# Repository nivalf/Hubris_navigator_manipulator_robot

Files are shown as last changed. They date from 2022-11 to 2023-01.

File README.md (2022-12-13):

# Hubris_navigator_manipulator_robot
Task:
- Navigate to the white board
- Draw on the whiteboard
- Return home

## Navigation Modes:
### 1. Curved path
- Move forward in a calculated curved path
- On detecting black line turn left & orient the bot to 90 degree from the start position.
- Move forward and draw on the whiteboard
- Reverse the bot again in a clockwise curve followed by a counter clockwise turn to reach the next black line.
- On detecting black line orient 90 degree and move backwards to reach home

IR Sensors: to detect black line
Ultrasound Sensors: to slow down the bot at a set distance from the whiteboard
Encoders: for odemetry

### 2. Using IR & Ultrasonic
- Navigate in straight lines & make 90 degree turns. 
- Detect black lines using IR 
- Ultrasonic is used to slow down the bot at set distances

### 3. Using only Ultrasonic
- Navigation by only using ultrasonic sensor readings

### 4. Using only IR
- Line follower

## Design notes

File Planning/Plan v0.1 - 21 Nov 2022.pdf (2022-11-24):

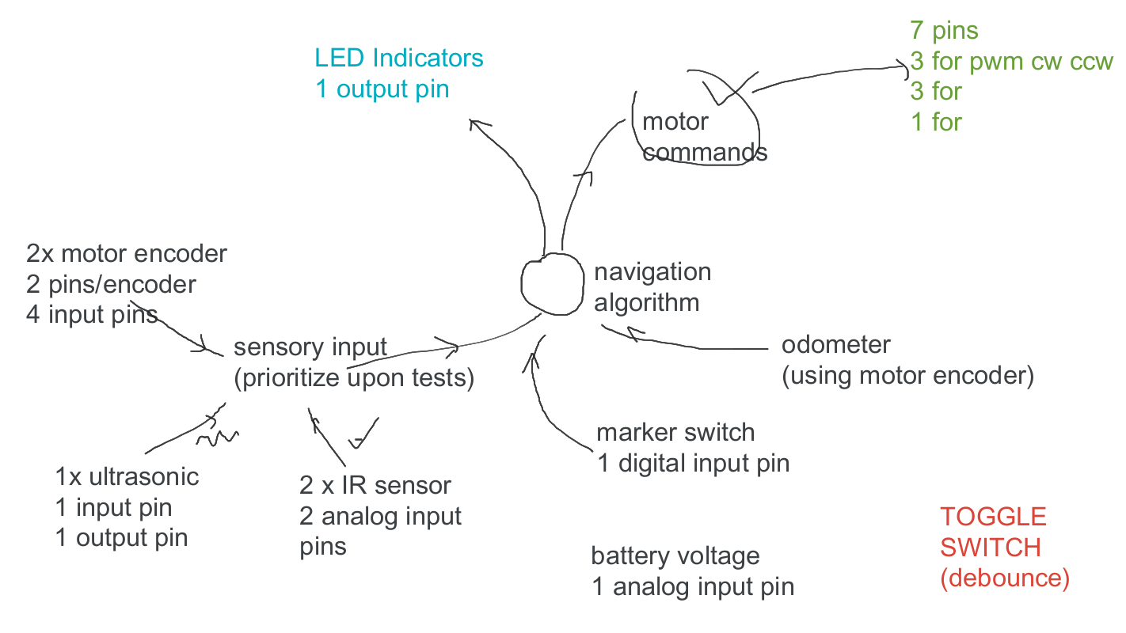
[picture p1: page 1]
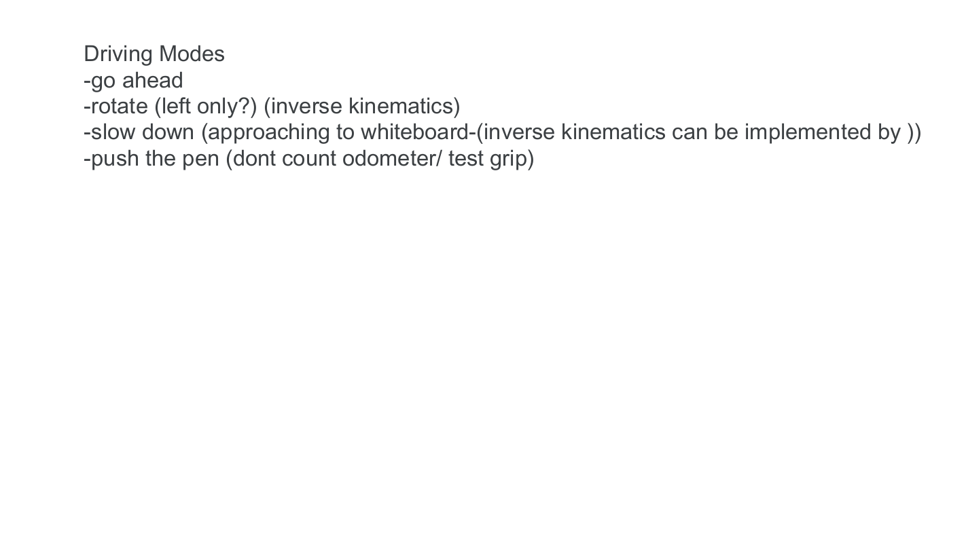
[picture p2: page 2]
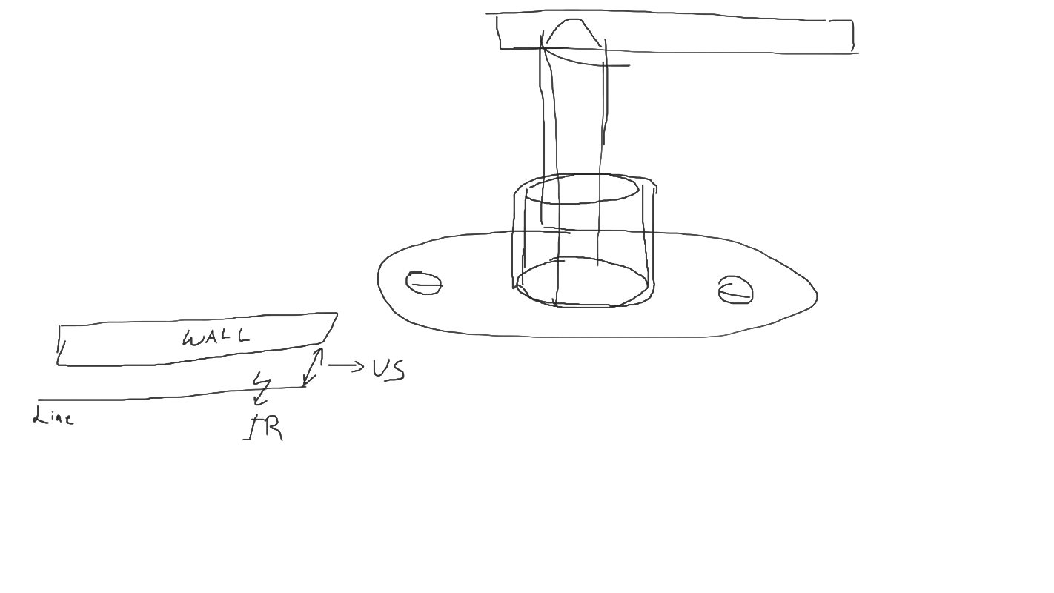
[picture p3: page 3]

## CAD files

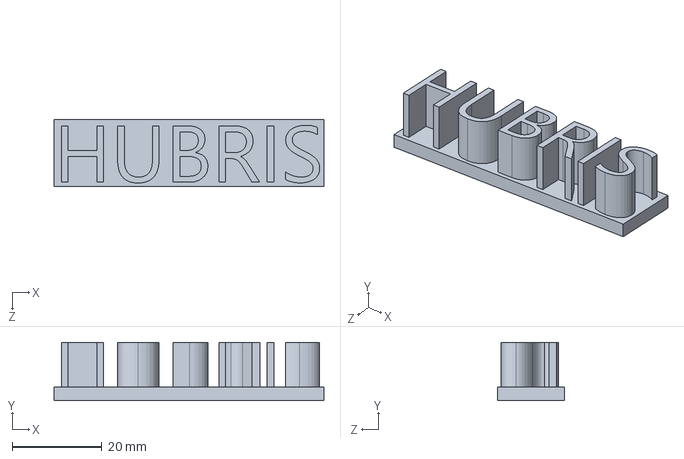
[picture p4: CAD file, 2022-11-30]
Design/CAD and DXF Files v4/Part2.SLDPRT
60.0 x 13.0 x 15.0 mm

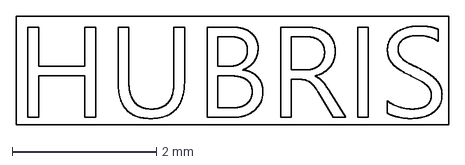
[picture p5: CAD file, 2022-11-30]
Design/CAD and DXF Files v4/Engraving.DXF
6.00 x 1.50 mm

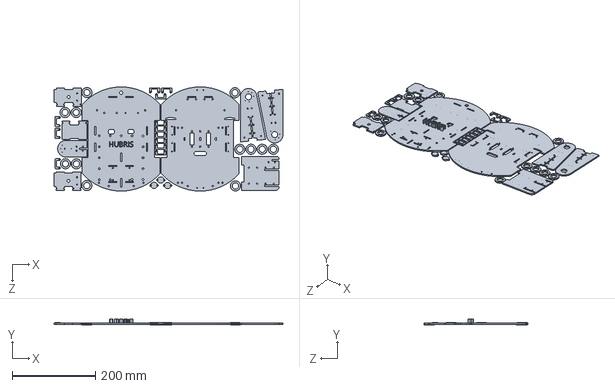
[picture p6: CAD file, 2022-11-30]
Design/CAD and DXF Files v4/lasercuttinglayout.SLDPRT
549.7 x 14.5 x 250.0 mm

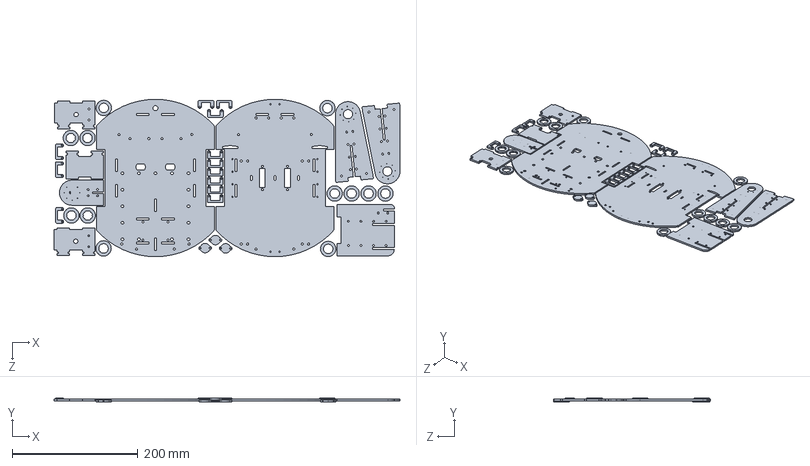
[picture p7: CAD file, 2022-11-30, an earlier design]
Design/CAD and DXF Files v2/lasercuttinglayout.SLDPRT
549.7 x 6.00 x 250.0 mm

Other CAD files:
Design/CAD and DXF Files v3/lasercuttinglayout.SLDPRT
Design/CAD and DXF Files/lasercuttinglayout.SLDPRT
Design/CAD and DXF Files v2/lasercuttinglayout.DXF
Design/CAD and DXF Files v3/lasercuttinglayout.DXF
Design/CAD and DXF Files v4/lasercuttinglayout.DXF
Design/CAD and DXF Files/lasercuttinglayout.DXF

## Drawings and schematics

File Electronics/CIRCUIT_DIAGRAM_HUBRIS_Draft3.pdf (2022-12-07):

## GND

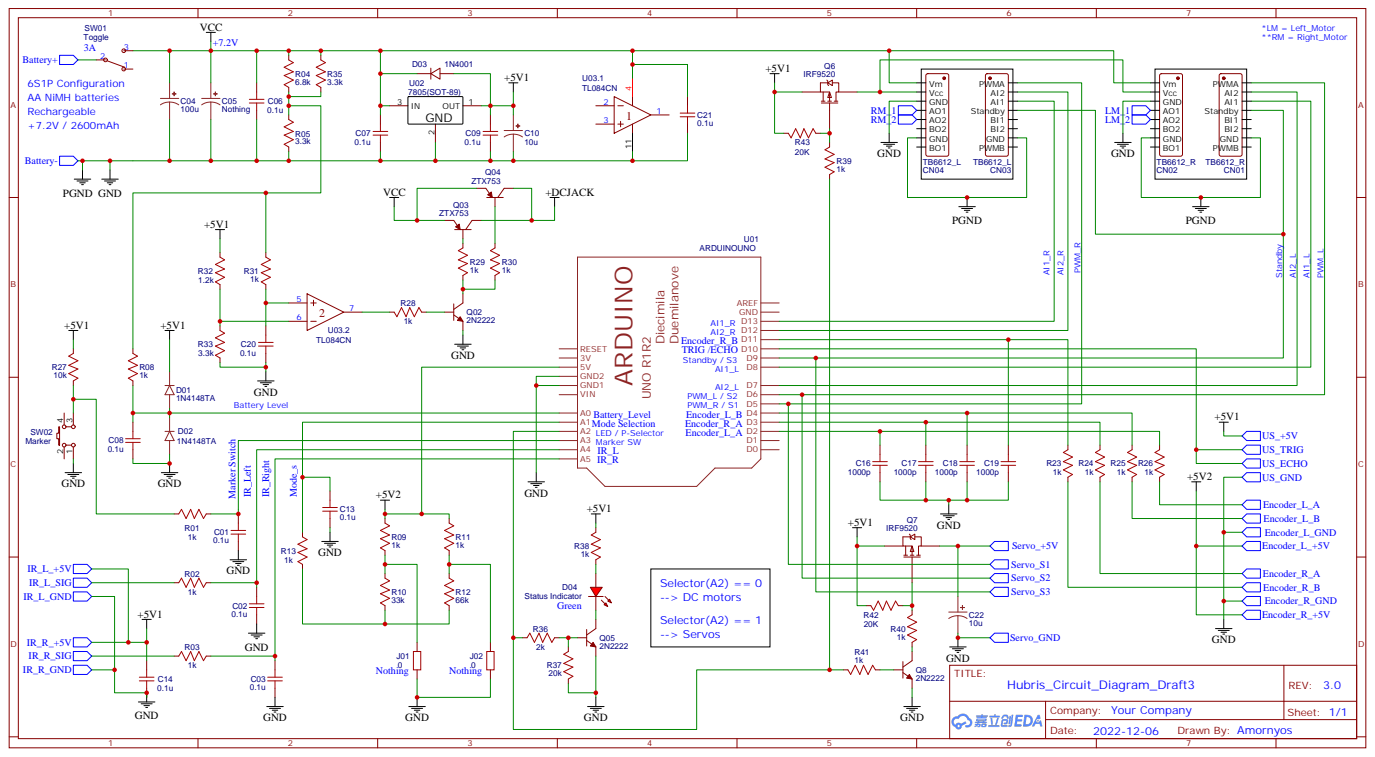
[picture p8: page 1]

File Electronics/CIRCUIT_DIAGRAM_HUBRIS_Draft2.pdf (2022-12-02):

## GND

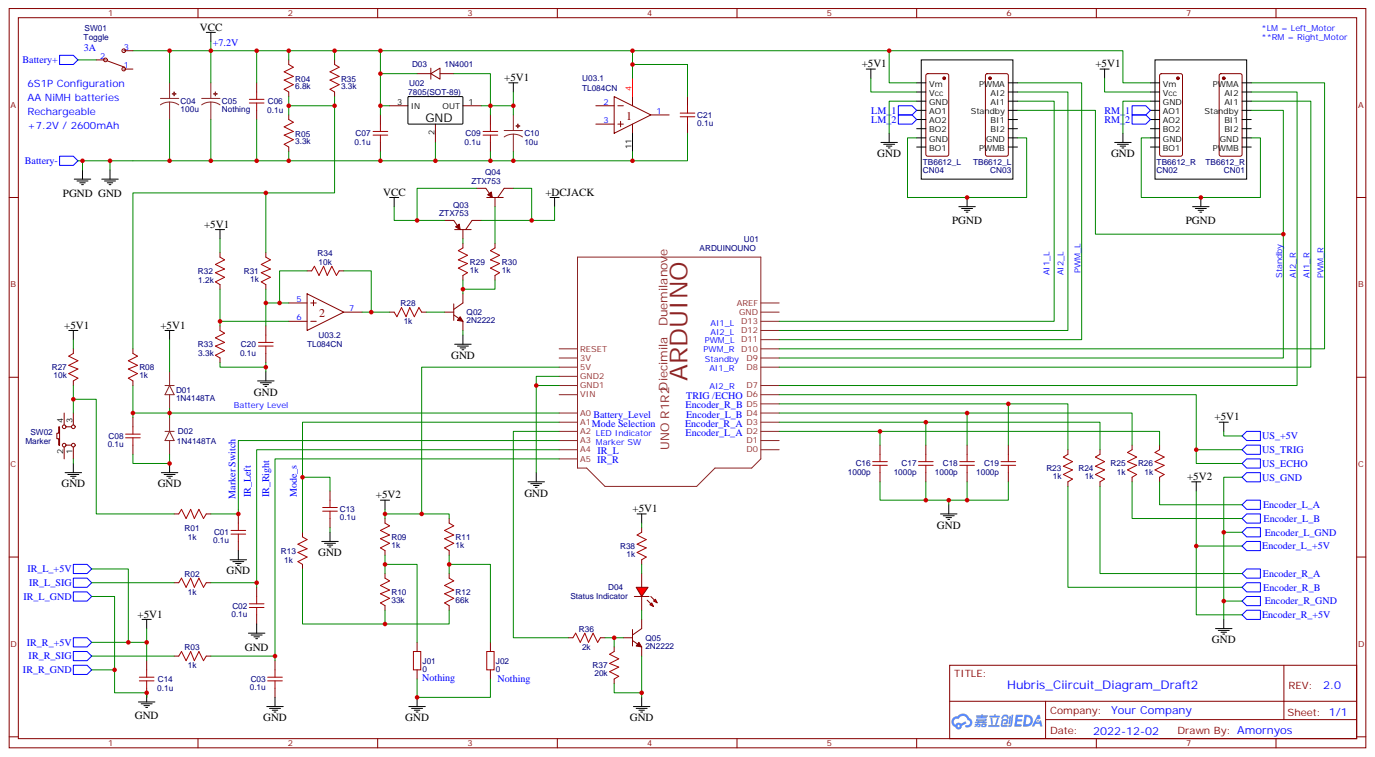
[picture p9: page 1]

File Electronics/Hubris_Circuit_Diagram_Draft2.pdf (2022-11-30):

## GND

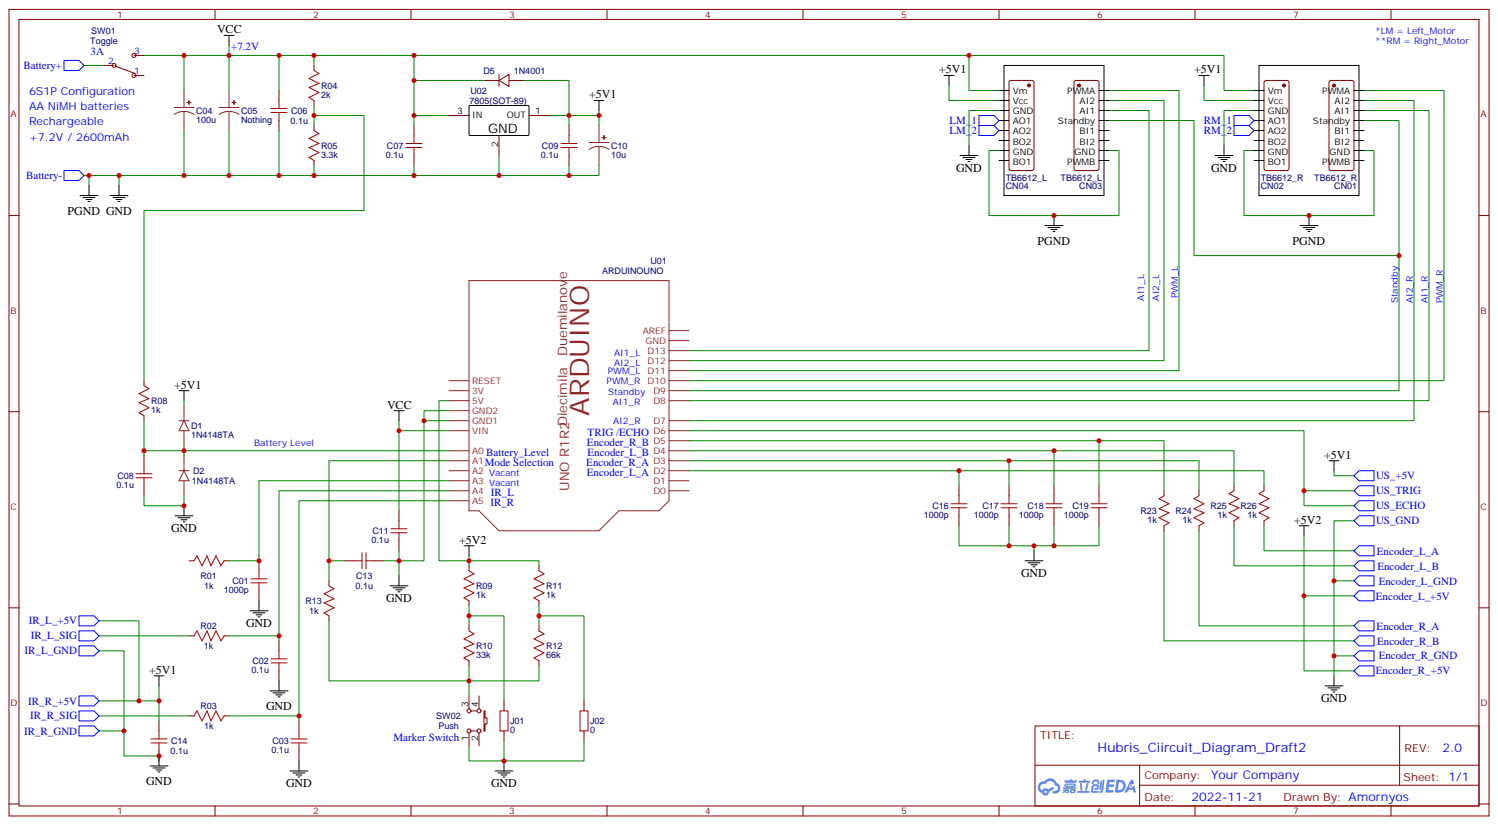
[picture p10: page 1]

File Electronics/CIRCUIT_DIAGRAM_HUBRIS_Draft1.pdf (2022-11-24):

## GND

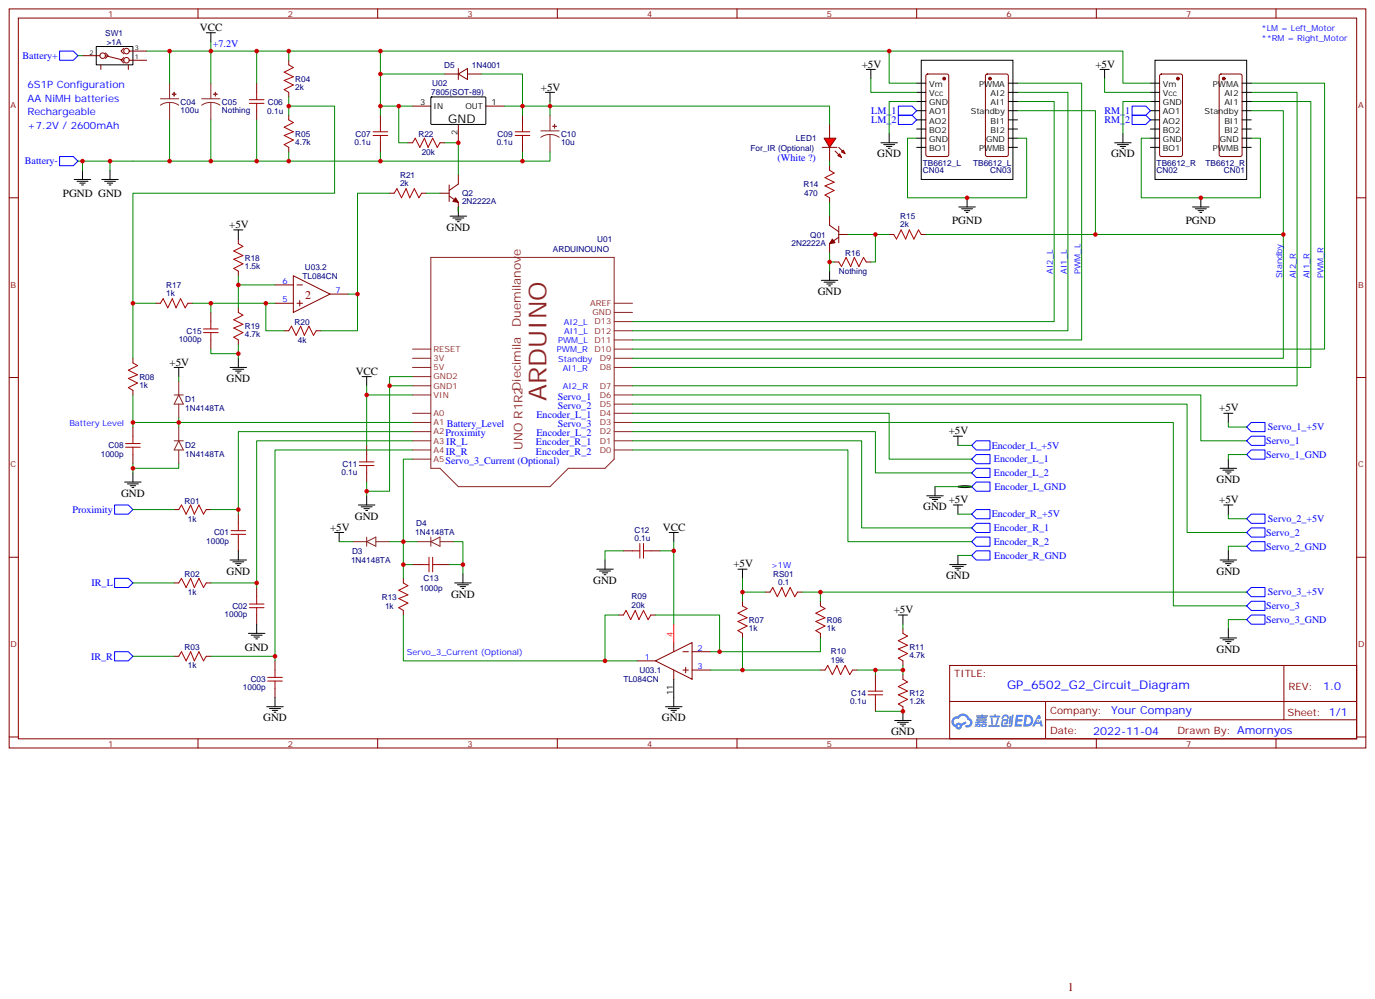
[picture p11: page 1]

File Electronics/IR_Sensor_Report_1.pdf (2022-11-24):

## Sharp's IR sensor performance evaluation report (1)

As the testing of IR sensor on the arena on the last Tuesday, It seemed that when the sensor passed through the black track, the ADC value would jump up from about 300 to 500 depend on the distance between sensors and the ground. (about 1.5 cm?) In this report, The closer of IR sensor to the track have been tested. And the result turned out that when the sensors passed through the black track, The ADC would drop from about 300 to 3 which is a big jump. This may help to decide the position of the sensors. The plotted results is shown in the second page.

Test condition 1 : 14.5 mm (1.45 cm)

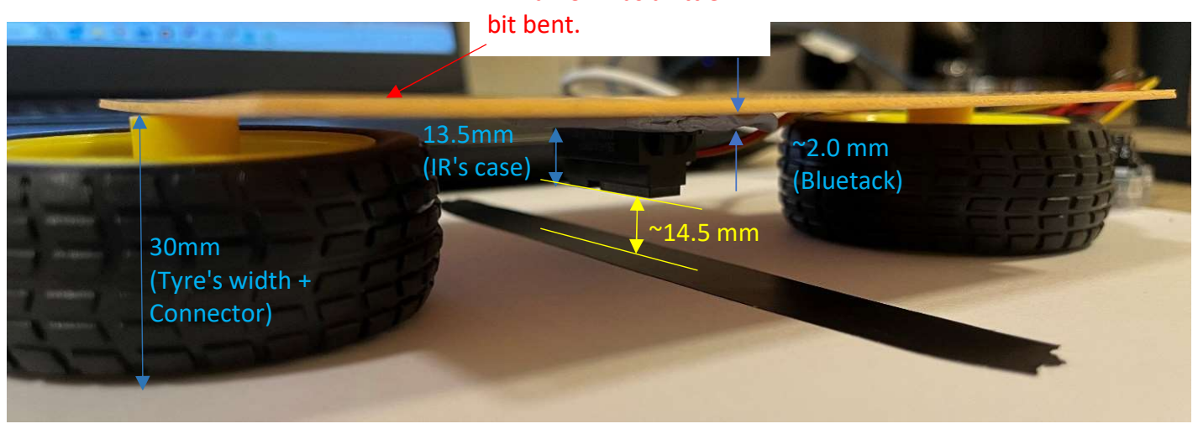
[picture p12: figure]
30mm (Tyre's width + Connector); 13.5mm (IR's case); ~2.0 mm (Bluetack); bit bent.

Test condition 2 : 11.5 mm (1.15cm)

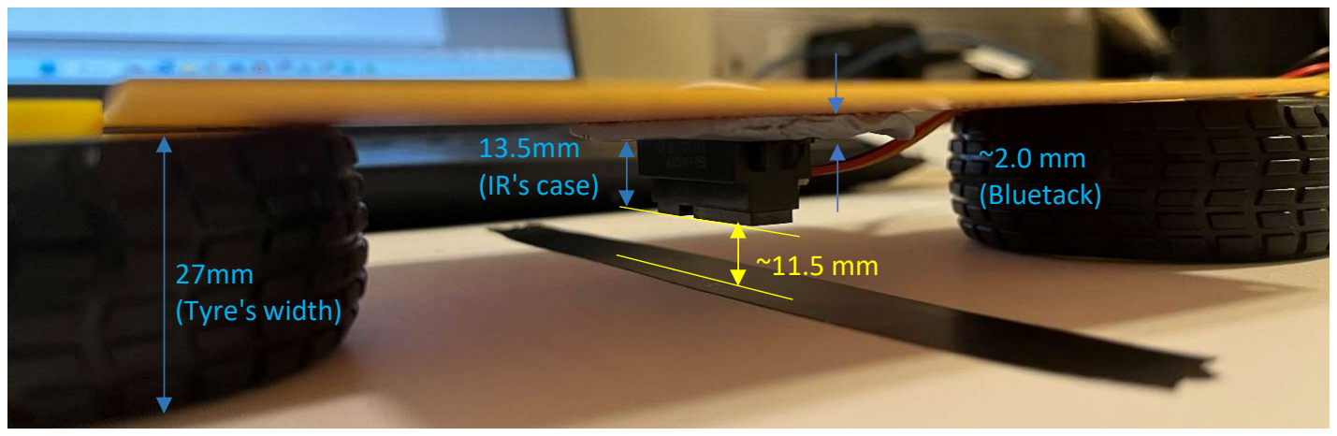
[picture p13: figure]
27mm (Tyre's width); 13.5mm (IR's case); ~2.0 mm (Bluetack)

Test condition 3 : 4.5mm (0.45cm)

*** a PCB was a little

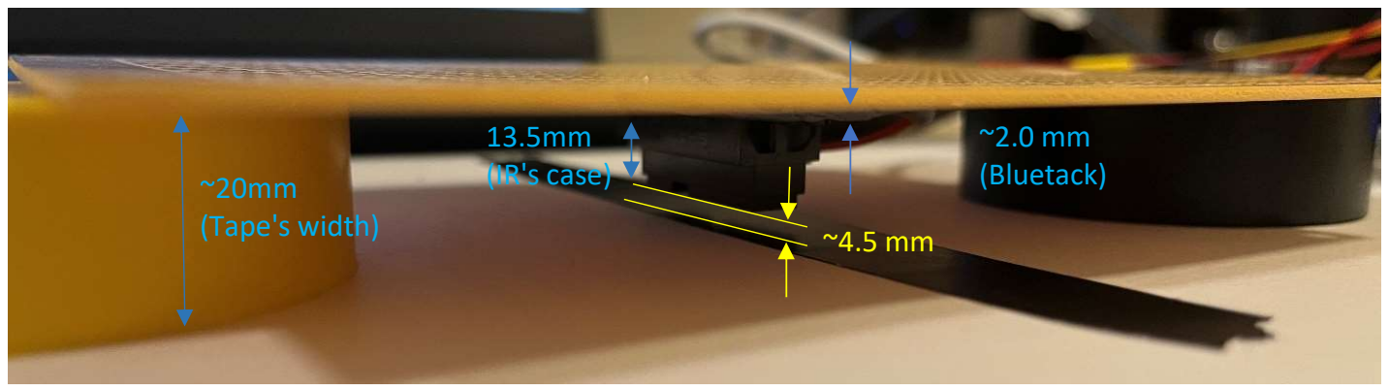
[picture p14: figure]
~20mm (Tape's width); 13.5mm (IR's case); ~2.0 mm (Bluetack)

## Test result

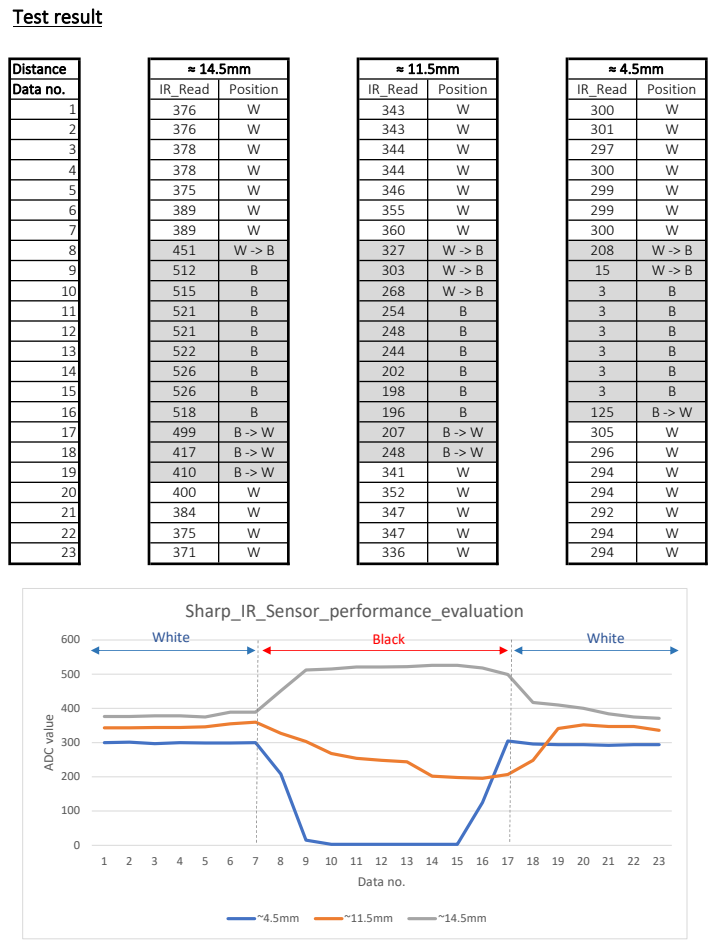
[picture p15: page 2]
Distance; Data no.; IR_Read; Position; 9 10 11 12 13 14 15 16 17 18 19 20 21 22 23 ADC value; Sharp_IR_Sensor_performance_evaluation; White; Black

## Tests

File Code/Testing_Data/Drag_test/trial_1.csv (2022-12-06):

Speed | Stopped_wheel | Encoder_R | Encoder_L | Rotation_R | Rotation_L | Stopped_wheel | Encoder_R | Encoder_L | Rotation_R | Rotation_L | Drag | Encoder_R | Encoder_L | Rotation_R | Rotation_L
20 | Right | 970 | 865 | 1.00 | 0.89 | Left | 975 | 970 | 1.01 | 1.00 | Drag | 0 | 1 | 0.00 | 0.00
30 | Right | 970 | 880 | 1.00 | 0.91 | Left | 983 | 970 | 1.01 | 1.00 | Drag | 0 | 8 | 0.00 | 0.01
40 | Right | 970 | 865 | 1.00 | 0.89 | Left | 994 | 970 | 1.02 | 1.00 | Drag | 0 | 15 | 0.00 | 0.02
50 | Right | 970 | 896 | 1.00 | 0.92 | Left | 1004 | 970 | 1.04 | 1.00 | Drag | 1 | 25 | 0.00 | 0.03
60 | Right | 970 | 881 | 1.00 | 0.91 | Left | 1016 | 970 | 1.05 | 1.00 | Drag | 2 | 32 | 0.00 | 0.03
70 | Right | 970 | 932 | 1.00 | 0.96 | Left | 999 | 970 | 1.03 | 1.00 | Drag | 25 | 48 | 0.03 | 0.05
80 | Right | 970 | 875 | 1.00 | 0.90 | Left | 1032 | 970 | 1.06 | 1.00 | Drag | 16 | 58 | 0.02 | 0.06
90 | Right | 970 | 869 | 1.00 | 0.90 | Left | 1041 | 970 | 1.07 | 1.00 | Drag | 24 | 61 | 0.02 | 0.06
100 | Right | 970 | 885 | 1.00 | 0.91 | Left | 1037 | 970 | 1.07 | 1.00 | Drag | 38 | 76 | 0.04 | 0.08
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

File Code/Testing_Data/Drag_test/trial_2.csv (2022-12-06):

Speed | Stopped_wheel | Encoder_R | Encoder_L | Rotation_R | Rotation_L | Stopped_wheel | Encoder_R | Encoder_L | Rotation_R | Rotation_L | Encoder_R_Drag | Encoder_L_Drag | Rotation_R_Drag | Rotation_L_Drag
20 | Right | 970 | 851 | 1.00 | 0.88 | Left | 974 | 970 | 1.00 | 1.00 | 0 | 2 | 0.00 | 0.00
30 | Right | 970 | 870 | 1.00 | 0.90 | Left | 984 | 970 | 1.01 | 1.00 | 0 | 8 | 0.00 | 0.01
40 | Right | 970 | 885 | 1.00 | 0.91 | Left | 994 | 970 | 1.02 | 1.00 | 0 | 16 | 0.00 | 0.02
50 | Right | 970 | 885 | 1.00 | 0.91 | Left | 1006 | 970 | 1.04 | 1.00 | 0 | 26 | 0.00 | 0.03
60 | Right | 970 | 892 | 1.00 | 0.92 | Left | 1013 | 970 | 1.04 | 1.00 | 5 | 36 | 0.01 | 0.04
70 | Right | 970 | 959 | 1.00 | 0.99 | Left | 980 | 970 | 1.01 | 1.00 | 44 | 51 | 0.05 | 0.05
80 | Right | 970 | 902 | 1.00 | 0.93 | Left | 1020 | 970 | 1.05 | 1.00 | 28 | 65 | 0.03 | 0.07
90 | Right | 970 | 888 | 1.00 | 0.92 | Left | 1033 | 970 | 1.06 | 1.00 | 35 | 69 | 0.04 | 0.07
100 | Right | 970 | 887 | 1.00 | 0.91 | Left | 1035 | 970 | 1.07 | 1.00 | 41 | 83 | 0.04 | 0.09
120 | Right | 970 | 909 | 1.00 | 0.94 | Left | 1023 | 970 | 1.05 | 1.00 | 85 | 110 | 0.09 | 0.11
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

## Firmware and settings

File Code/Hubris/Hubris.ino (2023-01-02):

#include "Robot.h"
#include "Constants.h"

// IR pins
#define IRLeftAPin A5
#define IRRightAPin A4

#define markerSwitchPin A3
// BatteryVoltage
#define batteryVoltagePin A0
// use same pin for trig & echo
#define trigPin 10  // 6
#define echoPin 10

// pins for left motor
#define motorLeftPin1 7
#define motorLeftPin2 8
#define motorLeftStandbyPin 9
#define motorLeftPWMPin 6 //10
#define motorLeftEncoderChannel_A_Pin 2
#define motorLeftEncoderChannel_B_Pin 4
// pins for right motor
#define motorRightPin1 12
#define motorRightPin2 13
#define motorRightStandbyPin 9
#define motorRightPWMPin 5 // 11
#define motorRightEncoderChannel_A_Pin 3
#define motorRightEncoderChannel_B_Pin 11 // 5

#define lineFollowSpeed 40

Robot Hubris(IRLeftAPin, IRRightAPin, trigPin, echoPin, motorLeftPin1, motorLeftPin2, motorLeftStandbyPin, motorLeftPWMPin, motorLeftEncoderChannel_A_Pin, motorLeftEncoderChannel_B_Pin, motorRightPin2, motorRightPin1, motorRightStandbyPin, motorRightPWMPin, motorRightEncoderChannel_A_Pin, motorRightEncoderChannel_B_Pin, batteryVoltagePin, markerSwitchPin);

long timestamp;
int count = 0;

// ISRs : Interrupt Service Routines
void motorLeftISR() {
  Hubris.countLeftEncoderChannel_A();
}

void motorRightISR() {
  Hubris.countRightEncoderChannel_A();
}

void setup(void) {
  Serial.begin(9600);  // We'll send debugging information via the Serial monitor

  //Attaching interrupt to pins for encoder
  attachInterrupt(digitalPinToInterrupt(motorLeftEncoderChannel_A_Pin), motorLeftISR, RISING);
  attachInterrupt(digitalPinToInterrupt(motorRightEncoderChannel_A_Pin), motorRightISR, RISING);

  Hubris.init();

  // DEV NOTE: Remove when not testing
  delay(1000);
}

void loop(void) {
  /*  
    Write your code here. You may use to curePath.ino and the other .ino files for reference.
    However, it is not required to write another .ino file, instead the code can be written directly here. 

    Go through the libraries folder to find the classes for each component: Hubris, left motor, right motor.. Feel free to 
    play with the individual functions or write them from scratch. I thought to delete those functions before handing this 
    over to you, but instead it might be better to have them for reference. You can choose to rewrite or modify as required.

    Happy Coding!
  */
}

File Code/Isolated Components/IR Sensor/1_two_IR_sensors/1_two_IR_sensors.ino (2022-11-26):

 
int IR1AnalogPin = A4; // IR is connected to analog 1
int IR2AnalogPin = A5; // IR is connected to analog 1
float IR1Reading;      // the analog reading from the IR sensor
float IR2Reading;      // the analog reading from the IR sensor
 
void setup(void) {
  Serial.begin(9600);   // We'll send debugging information via the Serial monitor
}
 
void loop(void) {
  int count = 100;

  IR1Reading = 0;
  IR2Reading = 0;

  for(int i=0; i<count; i++) {
    IR1Reading += analogRead(IR1AnalogPin);
    IR2Reading += analogRead(IR2AnalogPin);
    delay(1);
  }

  // Get the average value
  IR1Reading = IR1Reading/count;
  IR2Reading = IR2Reading/count;
  
  Serial.print(IR1Reading);
  Serial.print(' ');
  Serial.print(IR2Reading);
  Serial.println(' ');
}

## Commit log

2022-11-24 Circuit diagram added, IR and ultrasonic codes added
2022-11-26 Class created for IR sensors
2022-11-26 Class Ultrasonic created
2022-11-26 Use single pin for ultrasonic reading
2022-11-26 Make the ultrasonic class inherited from NewPing
2022-11-26 Exponential avg filter added. Low pass filter added
2022-11-27 Motor class added
2022-11-28 Robot: Steering function added
    [lasercuttinglayout.DXF, lasercuttinglayout.SLDPRT]
2022-11-30 Line follower code with steering cooloff time
2022-11-30 Cad design files
    [Engraving.DXF, Part2.SLDPRT, lasercuttinglayout.DXF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]
2022-11-30 Motor encoders added
2022-11-30 encoder channel 1 & 2 renamed to A & B
2022-11-30 Expose functions to count the encoder values in left & right wheels in the robot class
2022-12-01 Battery library added: to check battery voltage
2022-12-01 Correction factor added for left motor
    [Hubris.ino]
2022-12-01 Trial with correction factors for encoder count
    [Hubris.ino]
2022-12-02 reset wheel encoders before & after the left turn. integrated into the turn left code
    [Hubris.ino]
2022-12-02 Turn bot left: stop individual wheels once quarter turn is completed. - Calibrate the quarter wheel length
2022-12-02 Do task using ultrasonic mode
2022-12-02 Circuit diagram updates
2022-12-02 Navigate arena using Ultrasonic
2022-12-02 Battery volt code updated, reOrient use changed
2022-12-03 Navigate using IR & ultrasonic
2022-12-06 Testing code added
    [trial_1.csv, trial_2.csv, trial_3.csv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]
2022-12-06 Add marker switch input. Tweak the correction factor for moving forward, turning and also the quarter spin circumference
    [Hubris.ino, IR_US_operate.ino]
2022-12-07 Pin updates for the hardware with servo
2022-12-07 Steering factor constant added
